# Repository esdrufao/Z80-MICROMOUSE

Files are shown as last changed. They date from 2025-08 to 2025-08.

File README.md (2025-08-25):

Este es un robot micromouse creado para la competicion en la OSHWDEM 2025,el uso de un microprocesador Z80A es meramente nostalgico y como reto personal.

This is a micromouse robot created for the competition at OSHWDEM 2025, the use of a Z80A microprocessor is merely nostalgic and as a personal challenge.

Il s'agit d'un robot micromouse créé pour la compétition OSHWDEM 2025, l'utilisation d'un microprocesseur Z80A est simplement nostalgique et comme un défi personnel.

這是為 OSHWDEM 2025 比賽創建的微型滑鼠機器人，使用 Z80A 微處理器只是懷舊和作為個人挑戰。

これは、OSHWDEM 2025 のコンテストのために作成されたマイクロマウス ロボットです。Z80A マイクロプロセッサの使用は、単に懐かしさからであり、個人的な挑戦としてです。

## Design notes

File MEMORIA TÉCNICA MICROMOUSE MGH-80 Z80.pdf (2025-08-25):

# MEMORIA TÉCNICA: MICROMOUSE MGH-

# 80 Z80

## Sistema de Navegación Autónoma con Procesador Z80

📋 Especificaciones Técnicas

Parámetro | Valor
CPU | Z80 @ 4MHz
I/O | 8255 PPI
Memoria | EPROM 8KB + RAM 8KB
Sensores | 4× TCRT5000 + 1 sensor suelo
Motores | 2× N20 con encoders
Alimentación | 5V DC @ 1.5A
Programación | Ensamblador Z80

🎯 Algoritmo de Navegación

┌─────────────────────────────────────┐

│ | ALGORITMO PRINCIPAL | │

├─────────────────────────────────────┤

│ 1. Lectura sensores (10ms) | │
│ 2. Detección de meta (sensor suelo) | │
│ 3. Decisión de movimiento | │
│ 4. Control de motores | │
│ 5. Feedback visual (LEDs) | │
│ 6. Bucle continuo | │

🧮 Mapa de Memoria

; ESPACIO DE MEMORIA

; 8000H - 8FFFH: Código en EPROM (4KB)

; 9000H - 9FFFH: Libre para expansión

; A000H - BFFFH: Datos y stack

; C000H - C002H: Variables del sistema

; C003H - DFFFH: Libre para algoritmos

🔌 Diagrama de Conexiones 8255

PUERTO A (00H) - CONTROL MOTORES:

Bit 0: Motor Izq Adelante

Bit 1: Motor Izq Atrás

Bit 2: Motor Der Adelante

Bit 3: Motor Der Atrás

PUERTO B (01H) - SENSORES TCRT5000:

Bit 0: Frontal Bit 1: Derecha

Bit 2: Izquierda Bit 3: Trasero

PUERTO C (02H) - LEDS + SENSOR SUELO:

Bits 0-6: LEDs de estado (salida)

Bit 7: Sensor suelo meta (entrada)

📊 Tabla de Estados - LEDs de Diagnóstico

LED | Estado | Significado
Bit 0 | ON | Sensor frontal activo
Bit 1 | ON | Sensor derecha activo
Bit 2 | ON | Sensor izquierda activo
Bit 3 | ON | Sensor trasero activo

LED | Estado | Significado
Bit 4 | ON | Motores adelante
Bit 5 | ON | Motores atrás
Bit 6 | ON | Giro derecha
Bit 7 | ON | Giro izquierda

⚡ Esquema de Alimentación

┌─────────────────────────────────────┐

│ | DIAGRAMA DE POTENCIA | │

├─────────────────────────────────────┤

│ Batería 7.4V → Regulador 5V → MGH-80 | │
│ | │
│ 5V → Z80 + 8255 + EPROM + RAM | │
│ 5V → Sensores TCRT5000 | │
│ 5V → Drivers motores (L298N) | │
│ Motores: Alimentación separada | │

🔧 Parámetros de Calibración

1. Reset del sistema
2. Configuración 8255 (A=out, B=in, C=out)
3. Limpieza de variables
4. Motores en paro
5. LEDs apagados
6. Espera 500ms estabilización
7. Inicio algoritmo principal

📈 Rendimiento Estimado

- Tiempo de respuesta: < 50ms
- Frecuencia de muestreo: 50Hz
- Consumo en reposo: 200mA
- Consumo en movimiento: 800mA
- Velocidad máxima: 0.5 m/s

🛠️ Herramientas de Desarrollo

ENSAMBLADOR: zasm v4.2

PROGRAMADOR: TL866II Plus

DEPURACIÓN: LEDs integrados + multímetro

TESTEO: Laberinto 16x16 celdas

📷 Checklist Final de Verificación

- EPROM grabada correctamente
- Sensores TCRT5000 calibrados
- Motores responden correctamente
- Sensor suelo detecta línea blanca
- LEDs de estado funcionando
- Consumo eléctrico dentro de límites
- Estructura mecánica estable

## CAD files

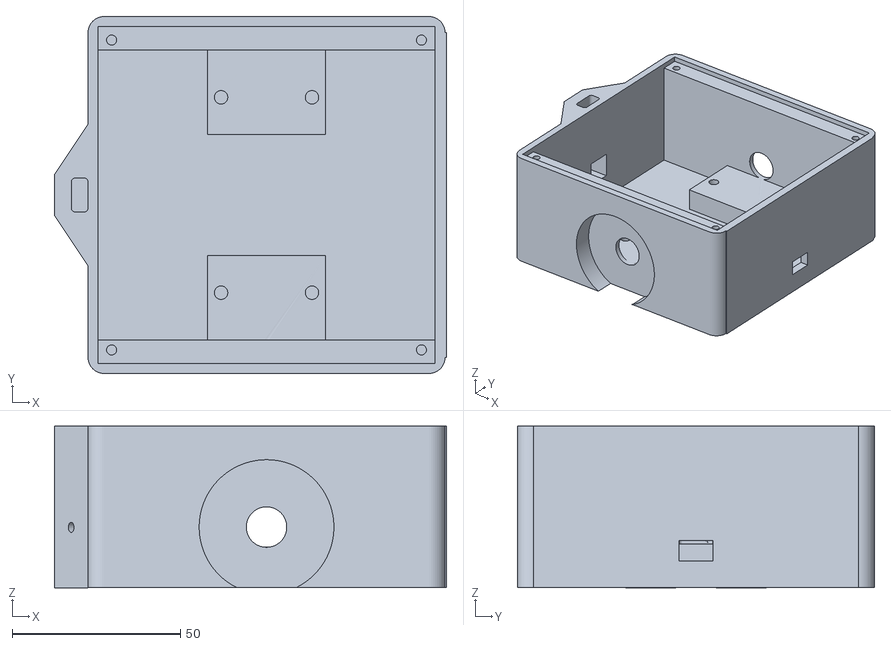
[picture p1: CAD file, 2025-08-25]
MGH-80 V2.stl
116.5 x 106.0 x 48.1
